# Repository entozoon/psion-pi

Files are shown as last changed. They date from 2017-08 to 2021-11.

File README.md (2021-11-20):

# Psion Pi

Personal electronics project; Attempting to build a modern PDA clamshell computer in a likeness of the venerable Psion 5mx.

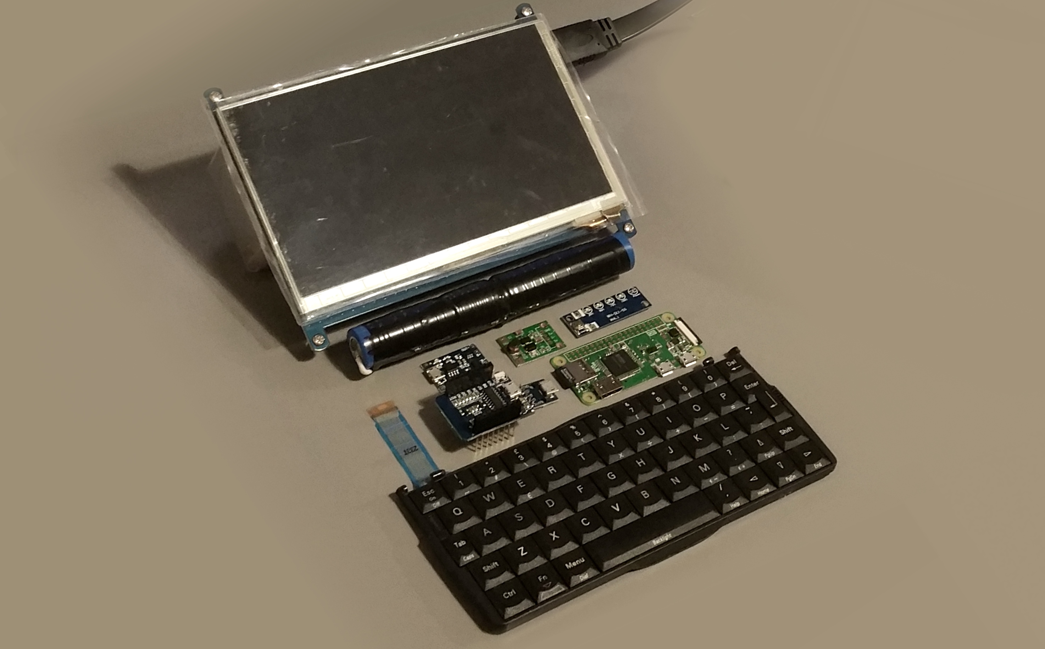
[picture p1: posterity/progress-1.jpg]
Knolling hard!


4 years into this project, some significant changes, namely wide screen, LG Phenom keyboard and Pi 4 (significantly more capable.. the previous Zero/Zero 2/3 all put me off)

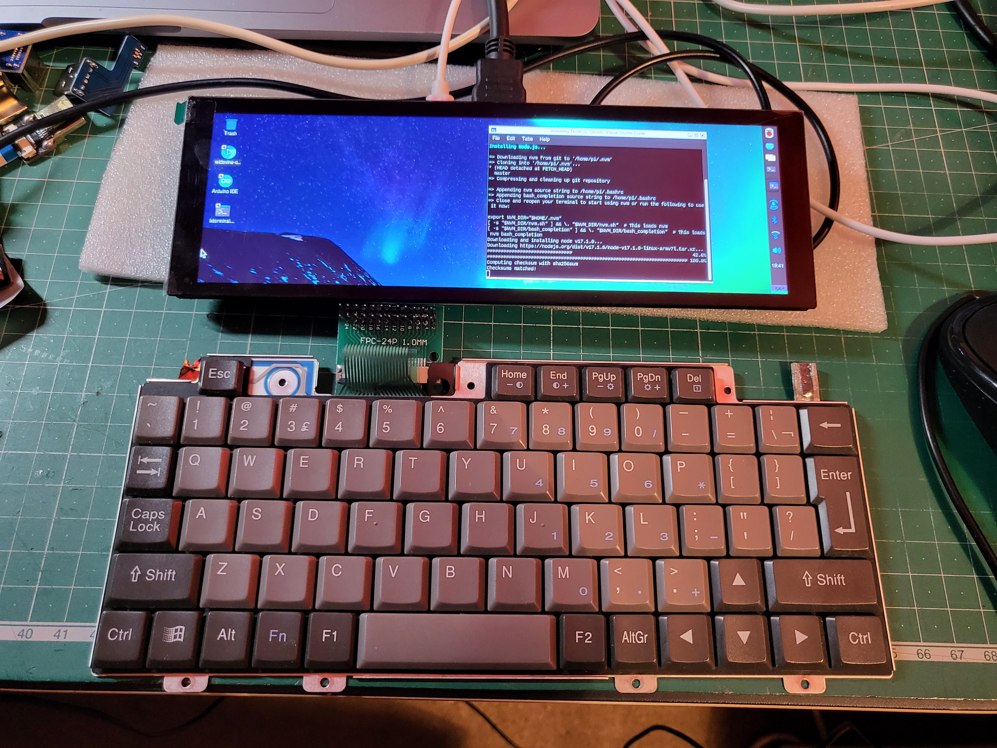
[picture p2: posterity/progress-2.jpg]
4 years later..


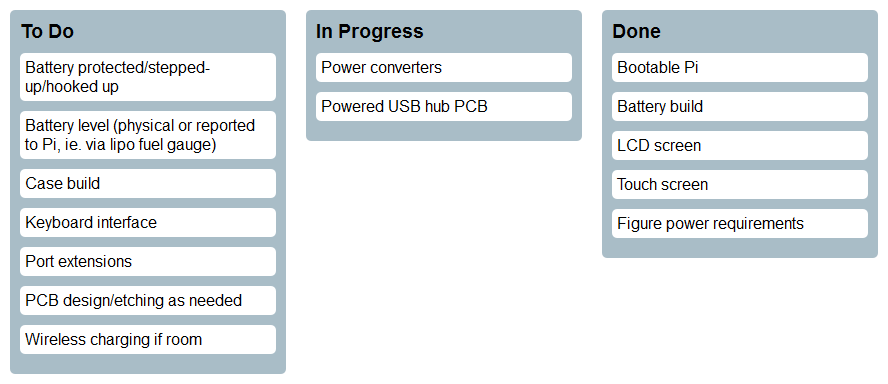
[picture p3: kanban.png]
created by readme-kanban-board


<!---KANBAN
# To Do
- Battery build protected/stepped-up/hooked up
- Battery level (physical or reported to Pi, ie. via lipo fuel gauge)
- Case build
- Keyboard scanning/emulation
- Wireless charging if possible

# In Progress
- Power converters

# Done
- Bootable Pi
- LCD screen
- Touch screen
- Figure power requirements
KANBAN--->

## Aims

- Tasty colour screen - For enjoyable video playback
- Quality keyboard - So it's legitimately useful
- Portability - I'm under no illusions that it'll be larger than a Psion 5mx/Jornada (as would be ideal) because of screen size and battery demands but if it's smaller than a Netbook Pro I'll be happy
- Sturdiness - Every single bit will be inherently fragile as heck, so I need to 3D print the structure real good

## Ingredients

- Battery pack (18650 3S parallel 3.7v) - Home-made li-ion for the win!
- Charging circuity and steps ups with protection - So I don't blow myself up
- Raspberry Pi
- LG Phenom keyboard, or maybe Psion Netbook (previously Psion 5mx, prepreviously Dell Foldable) - What? No way! Yes way. **Yes frickin way**
- Keyboard USB interface - Arduino or ESP8266, hand-built
- 7.9" Capacitive Touchscreen LCD 1024\*600 (Waveshare C Rev2.1)
- Mad efficient 1337 OS and warez, legit IDE, etc - We'll start with vanilla Raspbian first though

## "Wait, so what's this repo even for then?"

Notes about how I set everything up for reference, config files, microcontroller code for keyboard interface, etc etc.

## Setting up the Pi

Raspbian Stretch (2017-08-16) did **not** work, no matter what (with Pi Zeroes).

Raspbian Jessie (2017-07-05) did though, but more recently..

Raspberry Pi OS Bullseye [(2021-11-08)](https://downloads.raspberrypi.org/raspios_lite_arm64/images/) is 64-bit(!)

Installed on a 16gb microSD with win32diskImager (or similar) then, _before removing_, (in the windows partition, or `/boot` on unix):

1. Create a blank file called `ssh` on it, e.g.

```bash
cd /d h:
echo > ssh
```

2. Create `wpa_supplicant.conf` containing:

```bash
country=US
ctrl_interface=DIR=/var/run/wpa_supplicant GROUP=netdev
update_config=1

network={
 ssid="NetworkName"
 scan_ssid=1
 psk="yourpassword"
 key_mgmt=WPA-PSK
}
```

3. Safely eject (they can become corrupt, trust)
4. Pop it in the Pi with HDMI and a keyboard; let it do its thing.

Any screen problems and it should still be SSH-able.

## LCD Screen - 7.9" Waveshare Widescreen 400×1280

### Enable HDMI current and whatnot

```bash
sudo nano /boot/config.txt
```

```bash
# Add support for 7.9" Waveshare LCD
# set current over USB to 1.2A
max_usb_current=1
hdmi_group=2
hdmi_mode=87
hdmi_timings=400 0 100 10 140 1280 10 20 20 2 0 0 0 60 0 43000000 3
# 1: 90°; 2: 180°C; 3: 270° (might not work, see next section)
#lcd_rotate=3
#hdmi_enable_4kp60=1
```

### Disable compositor

```bash
sudo raspi-config
```

6 Advanced menu then A3 and set Compositor to disabled.

### Rotate

Set orientation (right) in raspbian `preferences > screen configuration`.
This appears to have a bug where the settings don't persist after boot - it creates a file called dispsetup.sh but doesn't appear to run after login, at least on my current distro, so let's force it:

```bash
sudo nano /etc/xdg/lxsession/LXDE-pi/autostart
```

Append:

```
@/usr/share/dispsetup.sh
```

## Touch Setup

Automatic and orientated by long-pressing the 'rotate touch' button on the screen.

## Brightness

Powers happily from the touch USB input!!

Has 5 Settings, long press on/off on screen:

- 1 0.15A
- 2 0.16A
- 3 0.17A
- 4 0.19A
- 5 0.2A

## Fan Shim

```bash
git clone https://github.com/pimoroni/fanshim-python
cd fanshim-python
sudo ./install.sh
cd examples
sudo ./install-service.sh --on-threshold 65 --off-threshold 55 --delay 2
```

## Overclock

Make sure to use the fan shim!

```bash
sudo nano /boot/config.txt
```

```
# Overclock (all values typically unset, defaulting to 700mhz)
over_voltage=4
arm_freq=2000
```

More steps involved.. https://www.tomshardware.com/how-to/raspberry-pi-4-23-ghz-overclock

## Other settings

Disable dimming, etc.. https://www.waveshare.com/wiki/7.9inch_HDMI_LCD

## Power Usage

| Component | Usage (Amps +/- 0.05) |
| ---: | --- |
| Pi Zero W | 0.15 (unused) |
| Pi 3 | 0.3 (idling) |
| Pi Zero 2 W | 0.3 |
| Pi Zero 2 W (Overclocked) | 0.45 |
| | |
| Pi 4 | 0.55 (idling) |
| 7.9" Screen | 0.65 |
| | |
| Total | 1.2 |

Battery life estimates, according to my **[Super Useful Tool](https://battery-life.netlify.com/)**:

18650 x 1 (2500mah) = ~1h

18650 x 3 (7500mah) = ~3h

Mine are 20A maximum discharge.
If they're in parallel, you get more mAh and current capability, as it's shared around.
And anyway, 20A discharge? Fokk man, it'll be nowhere near. I just need a nice chonky boost module.
If it doesn't work, build a series one with 15A BMS etc.

## Keyboard

I got reasonably far in this repo with keyboard emulation on the Pi itself but.. I don't love it, and since then I reckon I've nailed [keyboard matrix scanning](https://github.com/entozoon/print-me-beech/blob/master/print-me-beech/src/keyboard.h) so I plan to pick a microcotroller with suitably choppy USB capabilities (32u4/STM32/Tiny?) to capture the input and emulate a USB keyboard. Much cleaner!

## OBSOLETE: Previous foldable keyboard

Dell Axim X5 Foldable Keyboard - what a hero of a warlock of a battlemage of a keyboard!
Disassembling it revealed it only has three IO:

- 3.3V in
- GND
- Data out

  Hooking that all up to a USB FTDI (data => RX), reveals some useful output with the following settings (e.g. in RealTerm):
  Port -> Baud: 4800,
  Display -> Display As: Hex

### Keymap

This wonderous diagram is courtesy of [Gavin Whelan](https://ambientmemory.com/), along with generally pointing me in the [right direction](https://ambientmemory.com/2017/02/20/dell-axim-x5-reverse-engineering/) to capture input.

    |------||------||------||------||------||------||------||------||------||------||------||-----||-----||--------|
    |  `~  ||  1!  ||  2@  ||  3#  ||  4$  ||  5%  ||  6^  ||  7&  ||  8*  ||  9(  ||  0)  || -_  ||  =+ ||  <-    |
    | 0ef1 || 16e9 || 1ee1 || 26d9 || 25da || 2ed1 || 36c9 || 3dc2 || 3ec1 || 46b9 || 45ba || 4e  ||  55 || 718e   |
    |      ||      ||      ||      ||      ||      ||      ||      ||      ||      ||      || b1  ||  aa ||        |
    |------||------||------||------||------||------||------||------||------||------||------||-----||-----||--------|
    |--------||------||------||------||------||------||------||------||------||------||------||-----||-----||------|
    |  ->|   ||  Q   ||  W   ||  E   ||  R   ||  T   ||  Y   ||  U   ||  I   ||  O   ||  P   || {   || }   ||  |\  |
    | 0df2   || 15ea || 1de2 || 24db || 2dd2 || 2cd3 || 35ca || 3cc3 || 43bc || 44bb || 4db2 || 54ab|| 5ba4|| 5da2 |
    |        ||      ||      ||      ||      ||      ||      ||      ||      ||      ||      || [   || ]   ||      |
    |--------||------||------||------||------||------||------||------||------||------||------||-----||-----||------|
    |----------||------||------||------||------||------||------||------||------||------||------||------||----------|
    |  caps    ||  A   ||  S   ||  D   ||  F   ||  G   ||  H   ||  J   ||  K   ||  L   ||  ;:  ||  '"  ||  enter   |
    | 58a7     || 1ce3 || 1be4 || 23dc || 2bd4 || 34cb || 33cc || 3bc4 || 42bd || 4bb4 || 4cb3 || 52ad || 5aa5     |
    |          ||      ||      ||      ||      ||      ||      ||      ||      ||      ||      ||      ||          |
    |----------||------||------||------||------||------||------||------||------||------||------||------||----------|
    |--------------||------||------||------||------||------||------||------||------||------||------||------||------|
    |  shift       ||  Z   ||  X   ||  C   ||  V   ||  B   ||  N   ||  M   ||  ,<  ||  .>  ||  /?  ||  ^   ||  rsh |
    | 12ed         || 1ae5 || 22dd || 21de || 2ad5 || 32cd || 31ce || 3ac5 || 41be || 49b6 || 4ab5 || 28d7 || 59a6 |
    |              ||      ||      ||      ||      ||      ||      ||      ||      ||      ||      ||  |   ||      |
    |--------------||------||------||------||------||------||------||------||------||------||------||------||------|
    |------||------||------||------||------------------------------||------||------||------||------||------||------|
    |  fn  || ctrl ||  win ||  ie  ||           space              || alt  || ctrl ||  del || <--  ||  |   ||  --> |
    | 02fd || 14eb || 07f8 || 708f ||           5ca3               || 11ee || 738c || 6699 || 5ea1 || 609f || 2fd0 |
    |      ||      ||      ||      ||                              ||      ||      ||      ||      ||  v   ||      |
    |------||------||------||------||------------------------------||------||------||------||------||------||------|

## OBSOLETE: Previous LCD screen attempts

### 7.9" on Pi Zero 2

GRAPHICS?
Apparently an advanced graphics thing? Needs experimentation though:

```bash
sudo nano /usr/share/X11/xorg.conf.d/99-fbturbo.conf
```

Comment out the line, a la:

```
#       Driver          "fbturbo"
```

TOUCH?

```bash
sudo apt-get install xserver-xorg-input-libinput
sudo mkdir /etc/X11/xorg.conf.d
sudo cp /usr/share/X11/xorg.conf.d/40-libinput.conf /etc/X11/xorg.conf.d/
sudo nano /etc/X11/xorg.conf.d/40-libinput.conf
```

Find the touchscreen section and add _one of_ the following lines, a la:

```bash
Section "InputClass"
        Identifier "libinput touchscreen catchall"
        MatchIsTouchscreen "on"
        # Option "CalibrationMatrix" "0 1 0 -1 0 1 0 0 1" # mykemod
        # Option "CalibrationMatrix" "0 1 0 -1 0 1 0 0 1" # mykemod 90 deg
        # Option "CalibrationMatrix" "-1 0 1 0 -1 1 0 0 1" # mykemod 180 deg
        Option "CalibrationMatrix" "0 -1 1 1 0 0 0 0 1" # mykemod 270 deg
        MatchDevicePath "/dev/input/event*"
        Driver "libinput"
EndSection
```

### 7" Waveshare

Either copy the `config.txt` in this repo, or bosh this stuff into yours (in windows partition or `/boot` on unix):

```bash
# Add support for Waveshare 7" capacitive Touch (C) v2.1
# set current over USB to 1.2A
max_usb_current=1

# overscan to adjust image position
overscan_left=0
overscan_right=0
overscan_top=0
overscan_bottom=0

# HDMI config
hdmi_drive=1
hdmi_ignore_edid=0xa5000080
hdmi_group=2
hdmi_mode=87

# 1024x600 display
hdmi_cvt=1024 600 60 6 0 0 0
```

### 5" model A screen

Elegoo, a cheaper version of Wavershare model A (not B)

```bash
cd ~
wget https://github.com/entozoon/psion-pi/raw/master/lib/LCD-show-170703.tar.gz
tar xzvf *.tar.gz
rm *.tar.gz
cd LCD-show/
chmod +x LCD5-show
./LCD5-show
```

### 3.5"

Raspbian Stretch (2017-11-29)

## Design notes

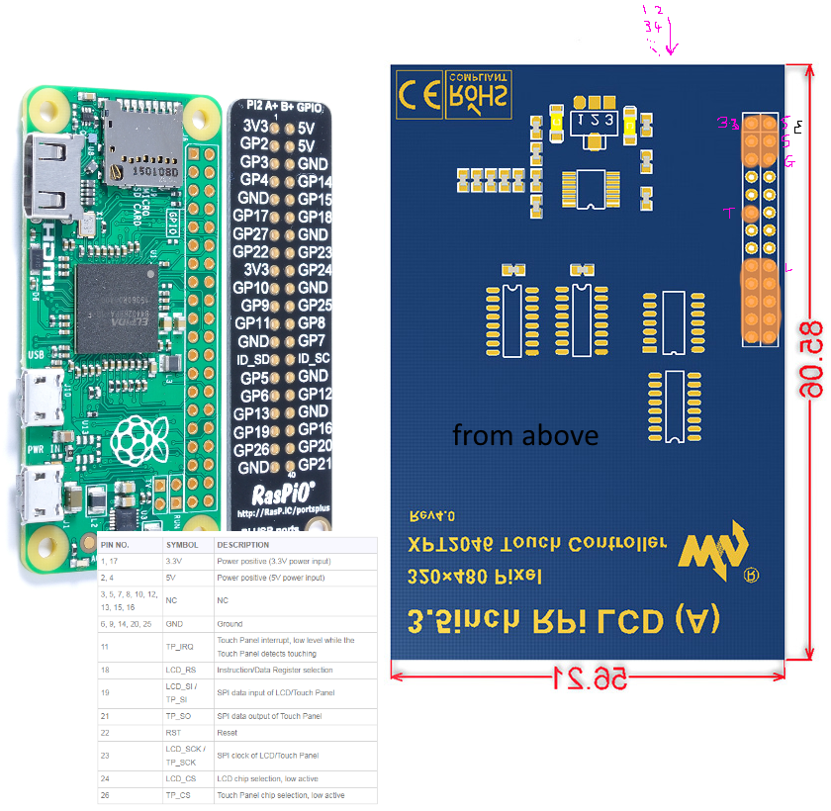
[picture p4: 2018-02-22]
3.5inchpins.png

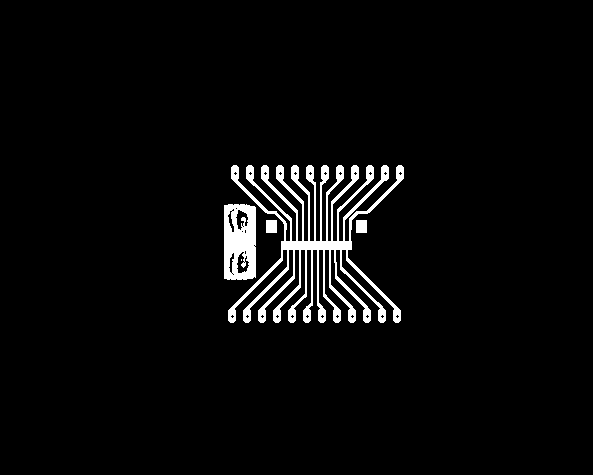
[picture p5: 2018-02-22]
pcb/keybint/export.png

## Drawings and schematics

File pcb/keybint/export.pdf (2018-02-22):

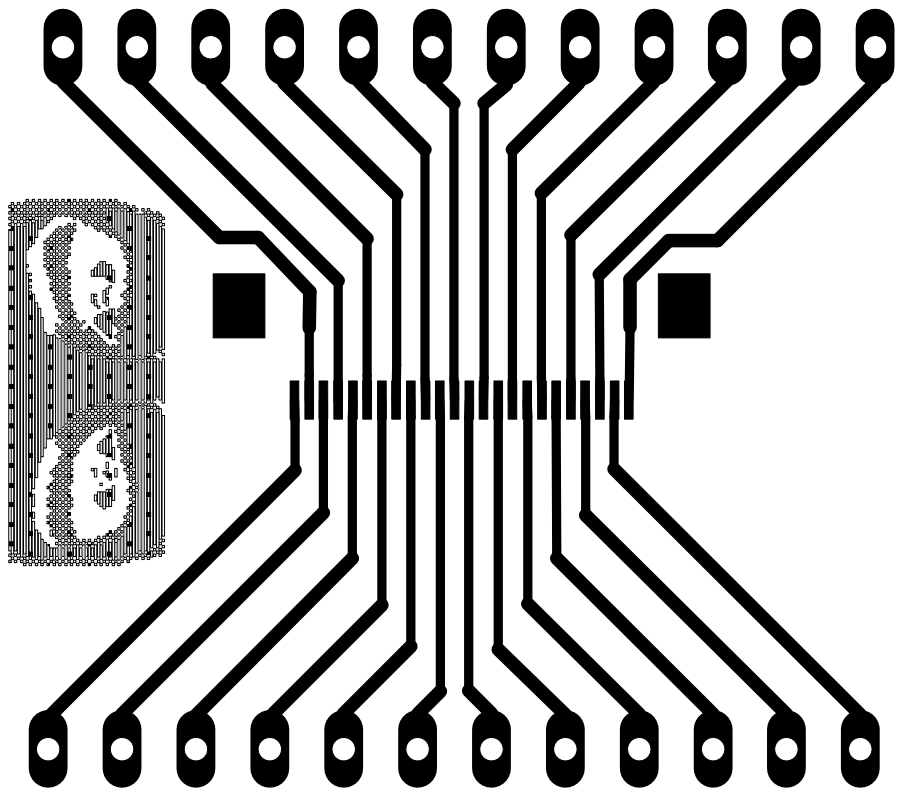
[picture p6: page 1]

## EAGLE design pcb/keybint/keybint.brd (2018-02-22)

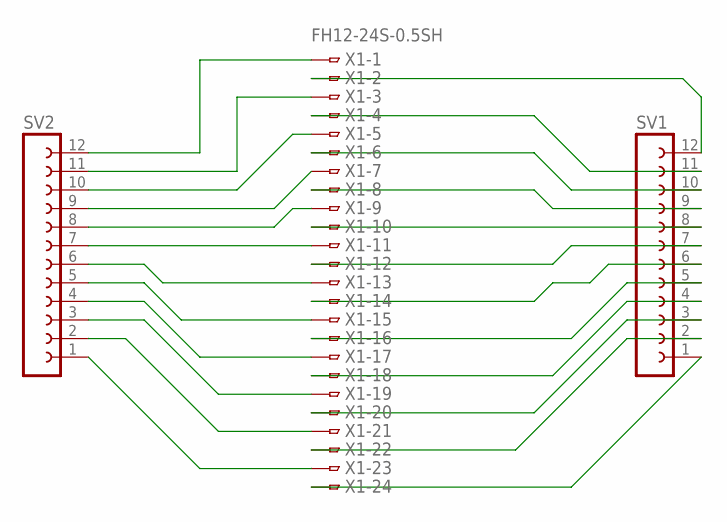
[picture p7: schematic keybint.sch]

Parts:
SV1, SV2: FE12-1; FE12
X1: FH12-24S-0.5SH

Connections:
unnamed: SV2.12, X1.1
unnamed: SV1.12, X1.2
unnamed: SV2.11, X1.3
unnamed: SV1.11, X1.4
unnamed: SV2.10, X1.5
unnamed: SV1.10, X1.6
unnamed: SV2.9, X1.7
unnamed: SV1.9, X1.8
unnamed: SV2.8, X1.9
unnamed: SV1.8, X1.10
unnamed: SV2.7, X1.11
unnamed: SV1.7, X1.12
unnamed: SV2.6, X1.13
unnamed: SV1.6, X1.14
unnamed: SV2.5, X1.15
unnamed: SV1.5, X1.16
unnamed: SV2.4, X1.17
unnamed: SV1.4, X1.18
unnamed: SV2.3, X1.19
unnamed: SV1.3, X1.20
unnamed: SV2.2, X1.21
unnamed: SV1.2, X1.22
unnamed: SV2.1, X1.23
unnamed: SV1.1, X1.24

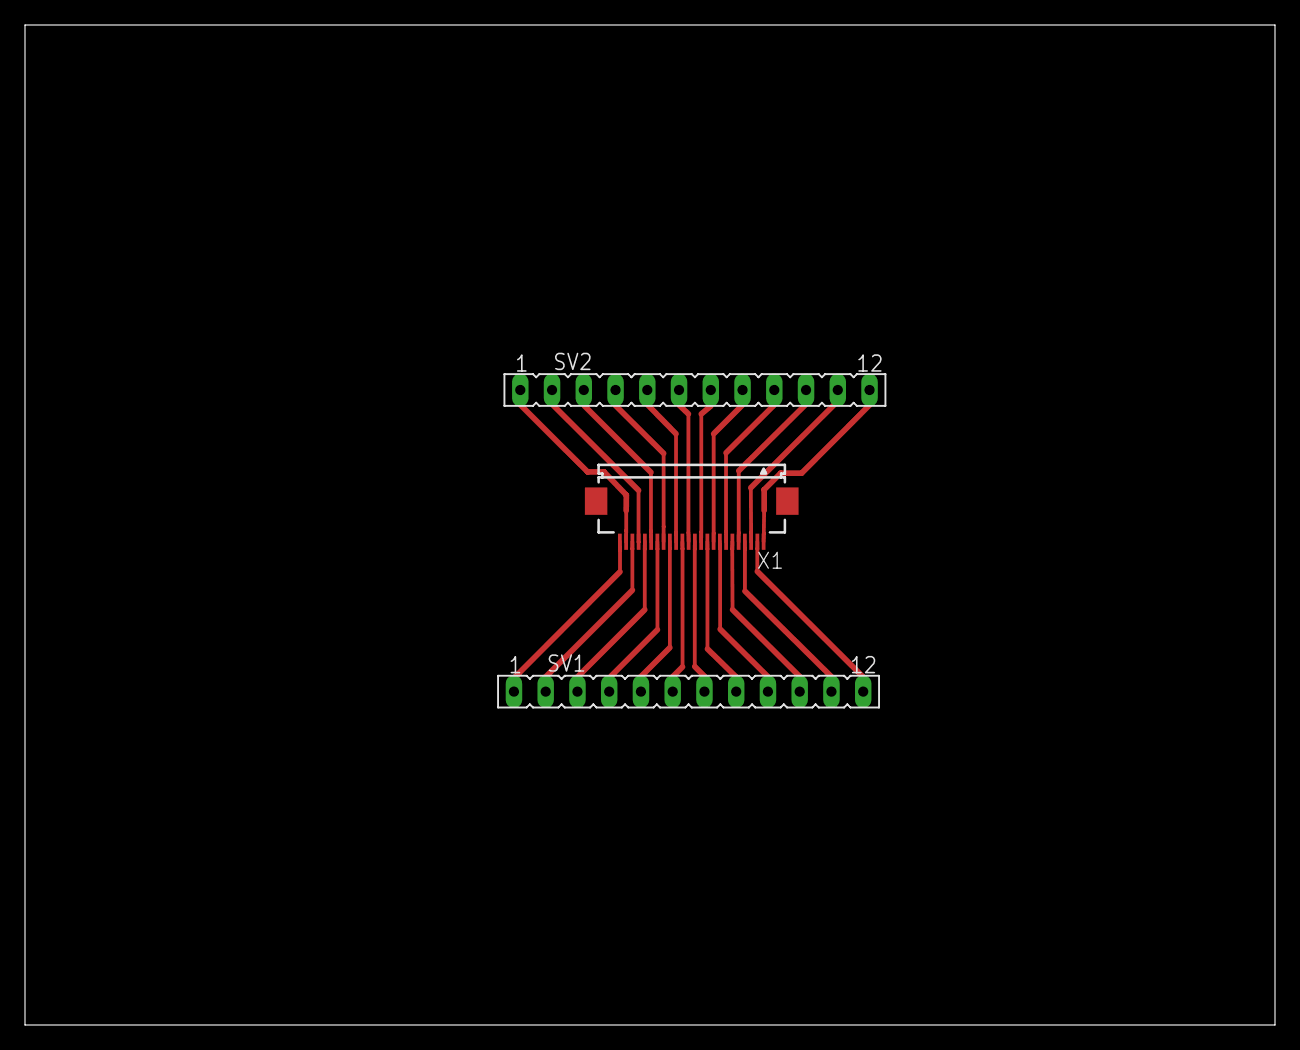
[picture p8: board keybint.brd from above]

Board: 2 copper layers, 100.0 x 80.0 mm, 3 parts (0 on the bottom side), 24 nets.

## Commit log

2017-08-31 Humble beginnings
    [config.txt]
2017-08-31 Pi setup and 7" LCD instructions (fingers crossed!)
    [config.txt]
2017-08-31 Aspect ratio tweak
    [config.txt]
2017-09-03 Thinking about power, hash tag yikes
    [config.txt]
2017-09-04 Battery stats
2017-09-10 Added 5" resistive touch notes
    [config.txt]
2017-09-20 Nothing really yet
    [motherboard.fzz]
2018-02-22 Getting somewhere with serial keyboard emulation and interface
    [keybint.brd, keybint.sch]
2019-04-23 Config update
    [config.txt]
2021-11-10 4 years later!
    [config.txt]
